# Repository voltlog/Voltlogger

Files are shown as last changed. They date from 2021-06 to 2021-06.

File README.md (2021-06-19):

# Voltlogger
This repository contains the source files for the Voltlogger, a 10 channel thermocouple data logger built around the ESP32 and the MAX31855 thermocouple interface chip. This project was shown in Voltlog #368.

## Known bugs in revA
Schematic constains a bug, where IO34 & IO35 are connected to chip select signals for thermocouple interface chips #1 and #2. These pins are input only on the ESP32 so they cannot drive the CS pis on Th1 & Th2. The workaround is to connect these CS pins to IO22 and IO23. ESD protection diodes seem to be causing signal integrity issues on the SD card interface so leave those unpopulated until this issue is debugged further.

More info about this project in [Voltlog #368](https://youtu.be/YB1_f1XHdw0).
If you would like to order one of these boards ready assembled, check out my [Tindie store](https://www.tindie.com/products/voltlog/voltlogger-10-channel-thermocouple-data-logger/).

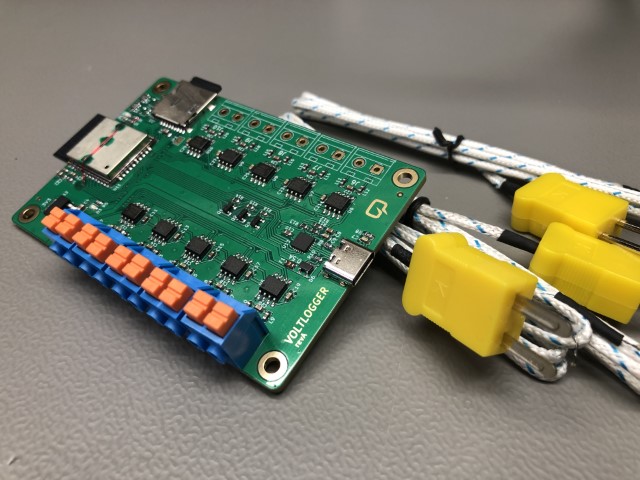
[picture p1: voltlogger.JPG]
Image of the assembled PCB


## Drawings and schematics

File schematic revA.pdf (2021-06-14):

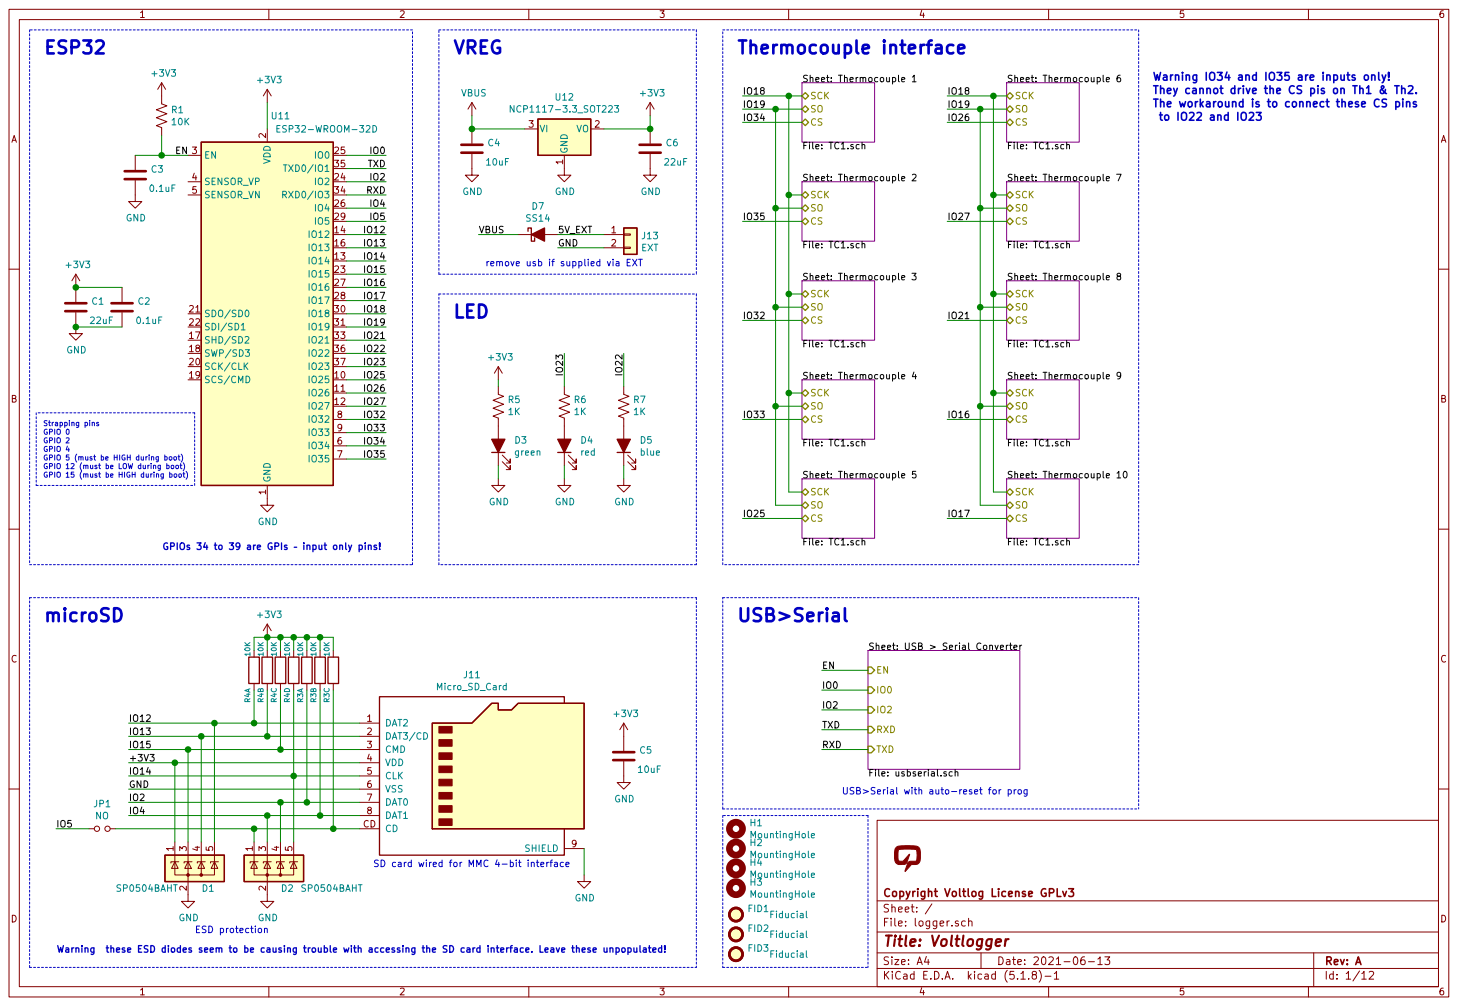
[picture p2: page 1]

Sheet: Thermocouple 1 File: TC1.sch SCK

Sheet: Thermocouple 6 File: TC1.sch SCK

Warning IO34 and IO35 are inputs only!
They cannot drive the CS pis on Th1 & Th2.
The workaround is to connect these CS pins

2 SCK/CLK 20 SDO/SD0 21 SDI/SD1 22

Sheet: Thermocouple 2 File: TC1.sch SCK

Sheet: Thermocouple 7 File: TC1.sch SCK

remove usb if supplied via EXT

Sheet: Thermocouple 3 File: TC1.sch SCK

Sheet: Thermocouple 8 File: TC1.sch SCK

Sheet: Thermocouple 4 File: TC1.sch SCK

Sheet: Thermocouple 9 File: TC1.sch SCK

Strapping pins GPIO 0 GPIO 2 GPIO 4 GPIO 5 (must be HIGH during boot) GPIO 12 (must be LOW during boot) GPIO 15 (must be HIGH during boot)

IO35 Warning these ESD diodes seem to be causing trouble with accessing the SD card interface. Leave these unpopulated!

Sheet: Thermocouple 5 File: TC1.sch SCK

Sheet: Thermocouple 10 File: TC1.sch SCK

Sheet: USB > Serial Converter File: usbserial.sch EN

USB>Serial with auto-reset for prog

File: logger.sch Sheet: / Copyright Voltlog License GPLv3

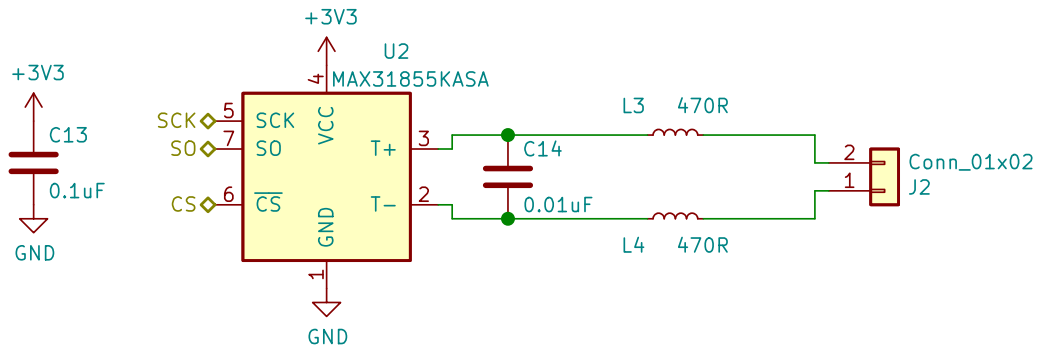
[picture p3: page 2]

4 SCK 5 CS 6 SO 7 U2 MAX31855KASA CS

Id: 2/12 Title: File: TC1.sch Sheet: /Thermocouple 2/

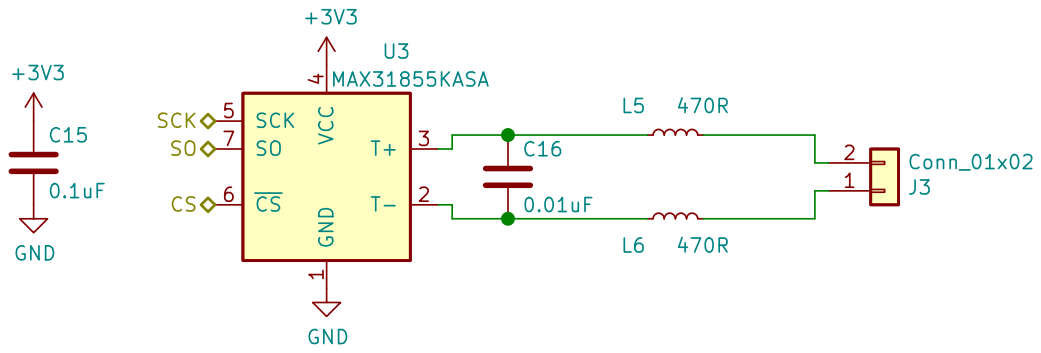
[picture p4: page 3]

4 SCK 5 CS 6 SO 7 U3 MAX31855KASA CS

Id: 3/12 Title: File: TC1.sch Sheet: /Thermocouple 3/

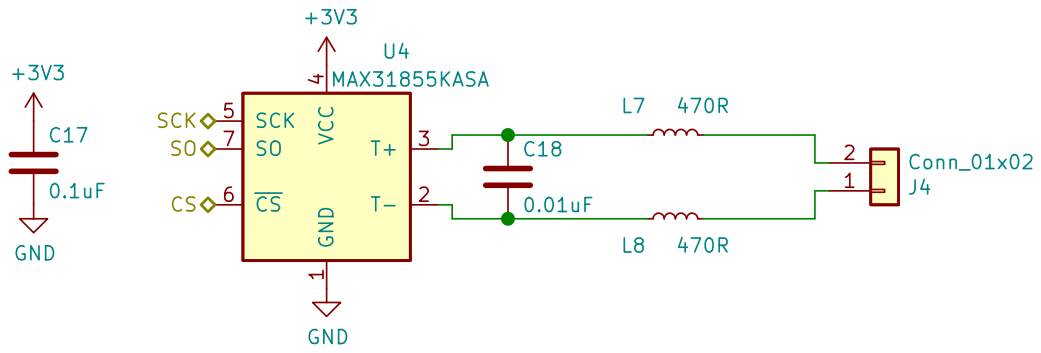
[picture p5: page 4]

4 SCK 5 CS 6 SO 7 U4 MAX31855KASA CS

Id: 4/12 Title: File: TC1.sch Sheet: /Thermocouple 4/

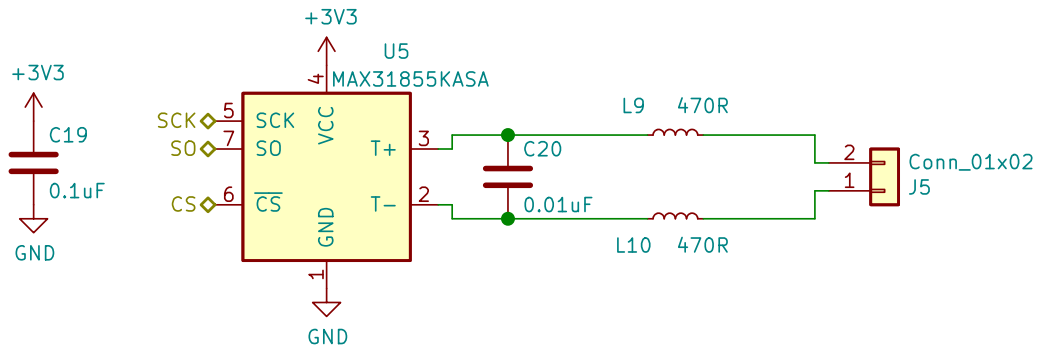
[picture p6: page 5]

4 SCK 5 CS 6 SO 7 U5 MAX31855KASA CS

Id: 5/12 Title: File: TC1.sch Sheet: /Thermocouple 5/

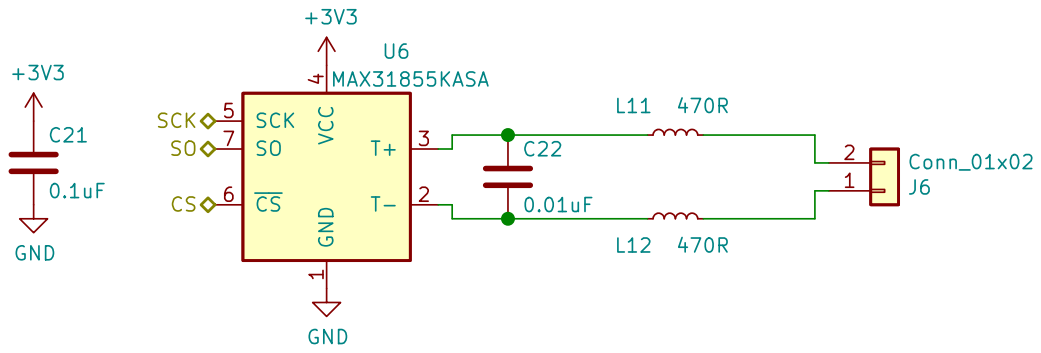
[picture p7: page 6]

4 SCK 5 CS 6 SO 7 U6 MAX31855KASA CS

Id: 6/12 Title: File: TC1.sch Sheet: /Thermocouple 6/

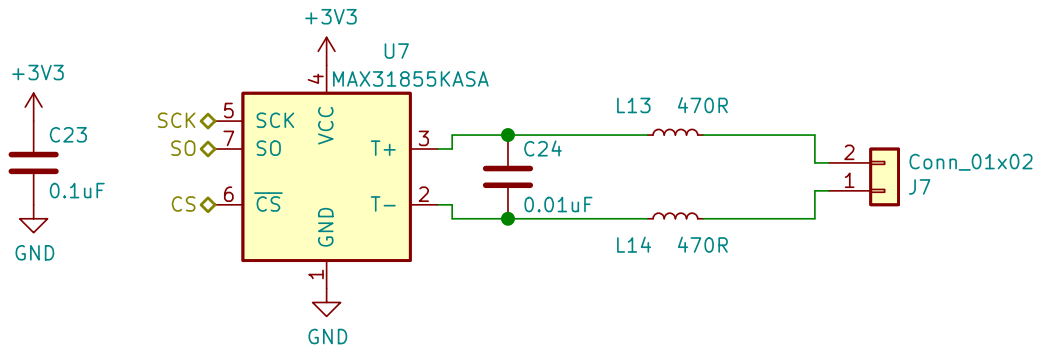
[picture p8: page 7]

4 SCK 5 CS 6 SO 7 U7 MAX31855KASA CS

Id: 7/12 Title: File: TC1.sch Sheet: /Thermocouple 7/

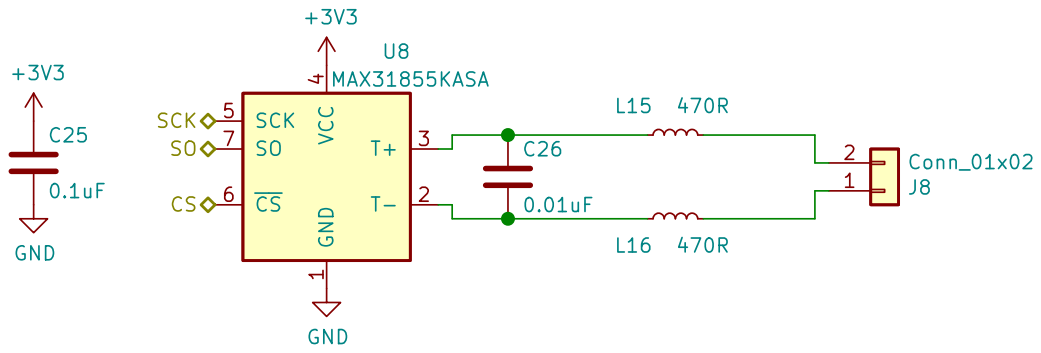
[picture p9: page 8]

4 SCK 5 CS 6 SO 7 U8 MAX31855KASA CS

Id: 8/12 Title: File: TC1.sch Sheet: /Thermocouple 8/

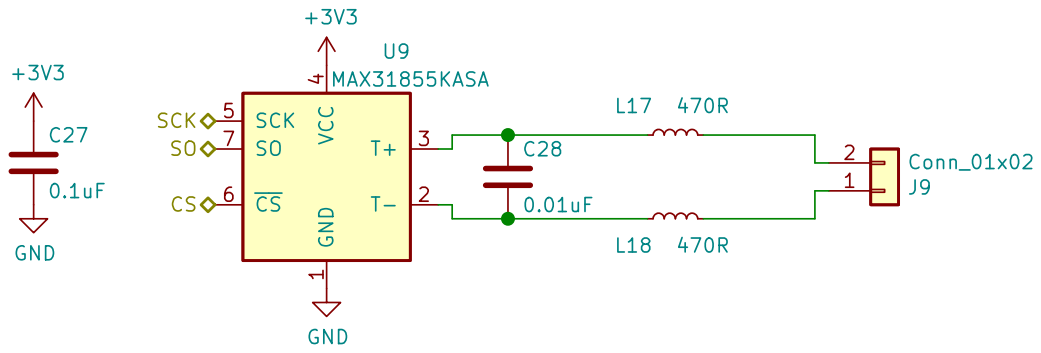
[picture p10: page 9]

4 SCK 5 CS 6 SO 7 U9 MAX31855KASA CS

Id: 9/12 Title: File: TC1.sch Sheet: /Thermocouple 9/

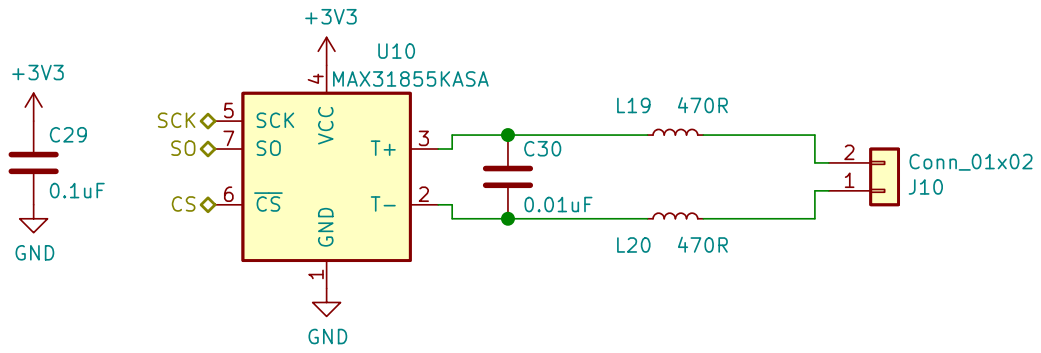
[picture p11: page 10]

4 SCK 5 CS 6 SO 7 U10 MAX31855KASA CS

Id: 10/12 Title: File: TC1.sch Sheet: /Thermocouple 10/

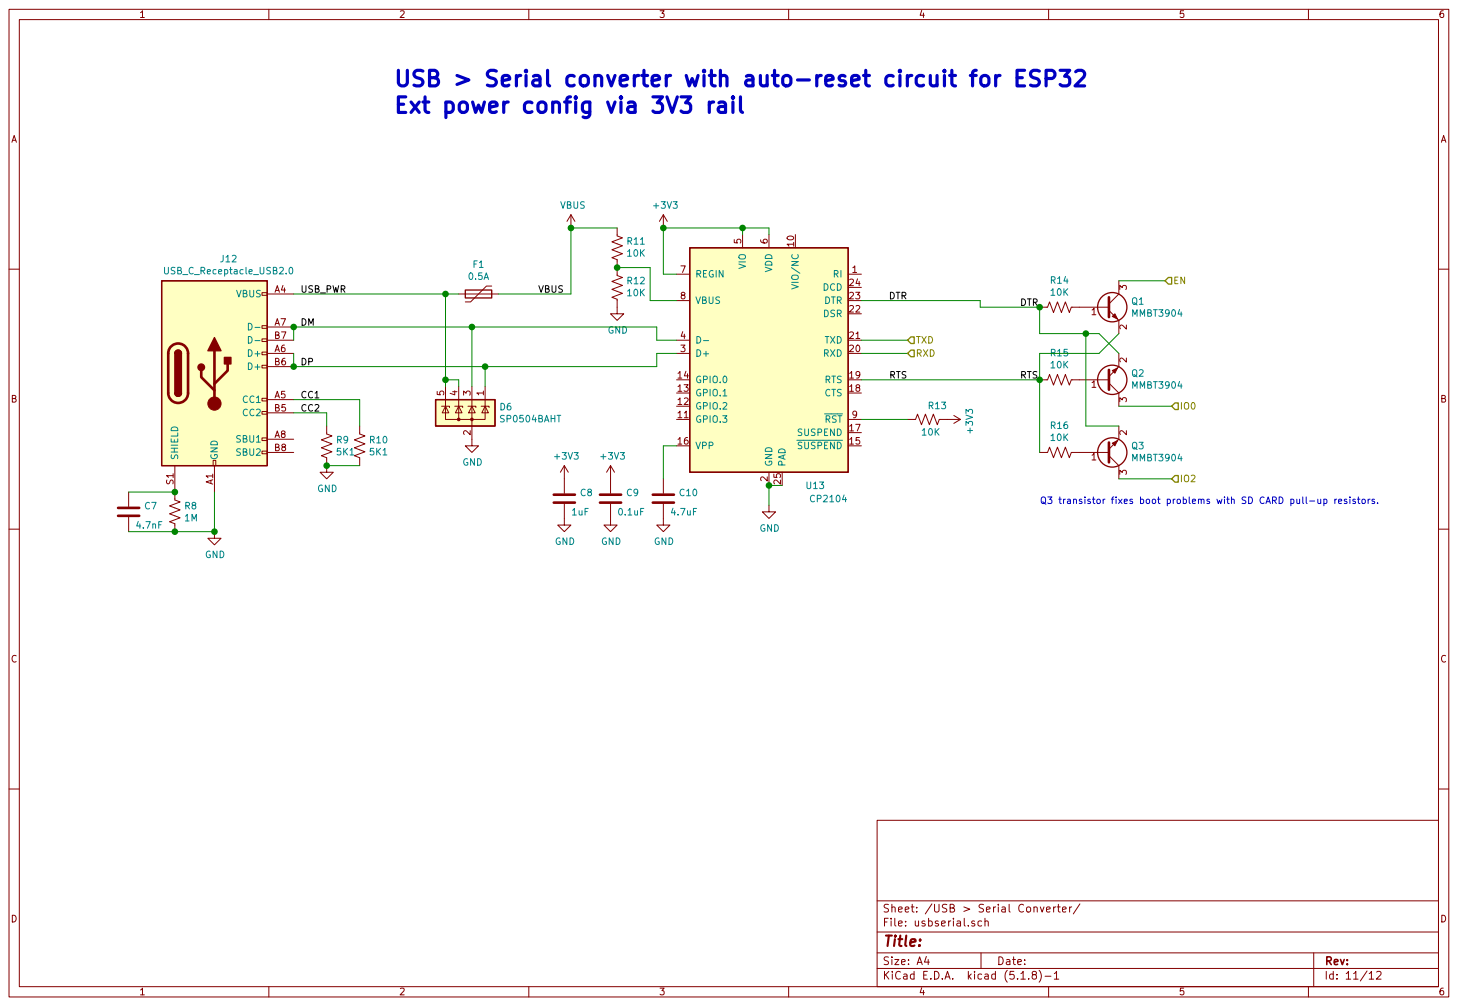
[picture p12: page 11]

Ext power config via 3V3 rail

6 REGIN 7 VBUS 8 RST 9 U13 CP2104 +3V3 GND

2 RXD 20 TXD 21 DSR 22 DTR 23 DCD 24 PAD 25 D+ 3 D- 4 VIO

Q3 transistor fixes boot problems with SD CARD pull-up resistors.

Id: 11/12 Title: File: usbserial.sch Sheet: /USB > Serial Converter/ GND

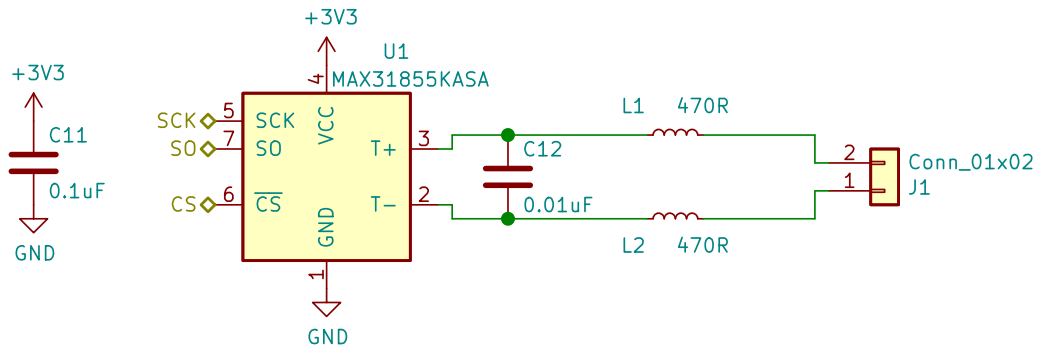
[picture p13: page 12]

4 SCK 5 CS 6 SO 7 U1 MAX31855KASA CS

Id: 12/12 Title: File: TC1.sch Sheet: /Thermocouple 1/

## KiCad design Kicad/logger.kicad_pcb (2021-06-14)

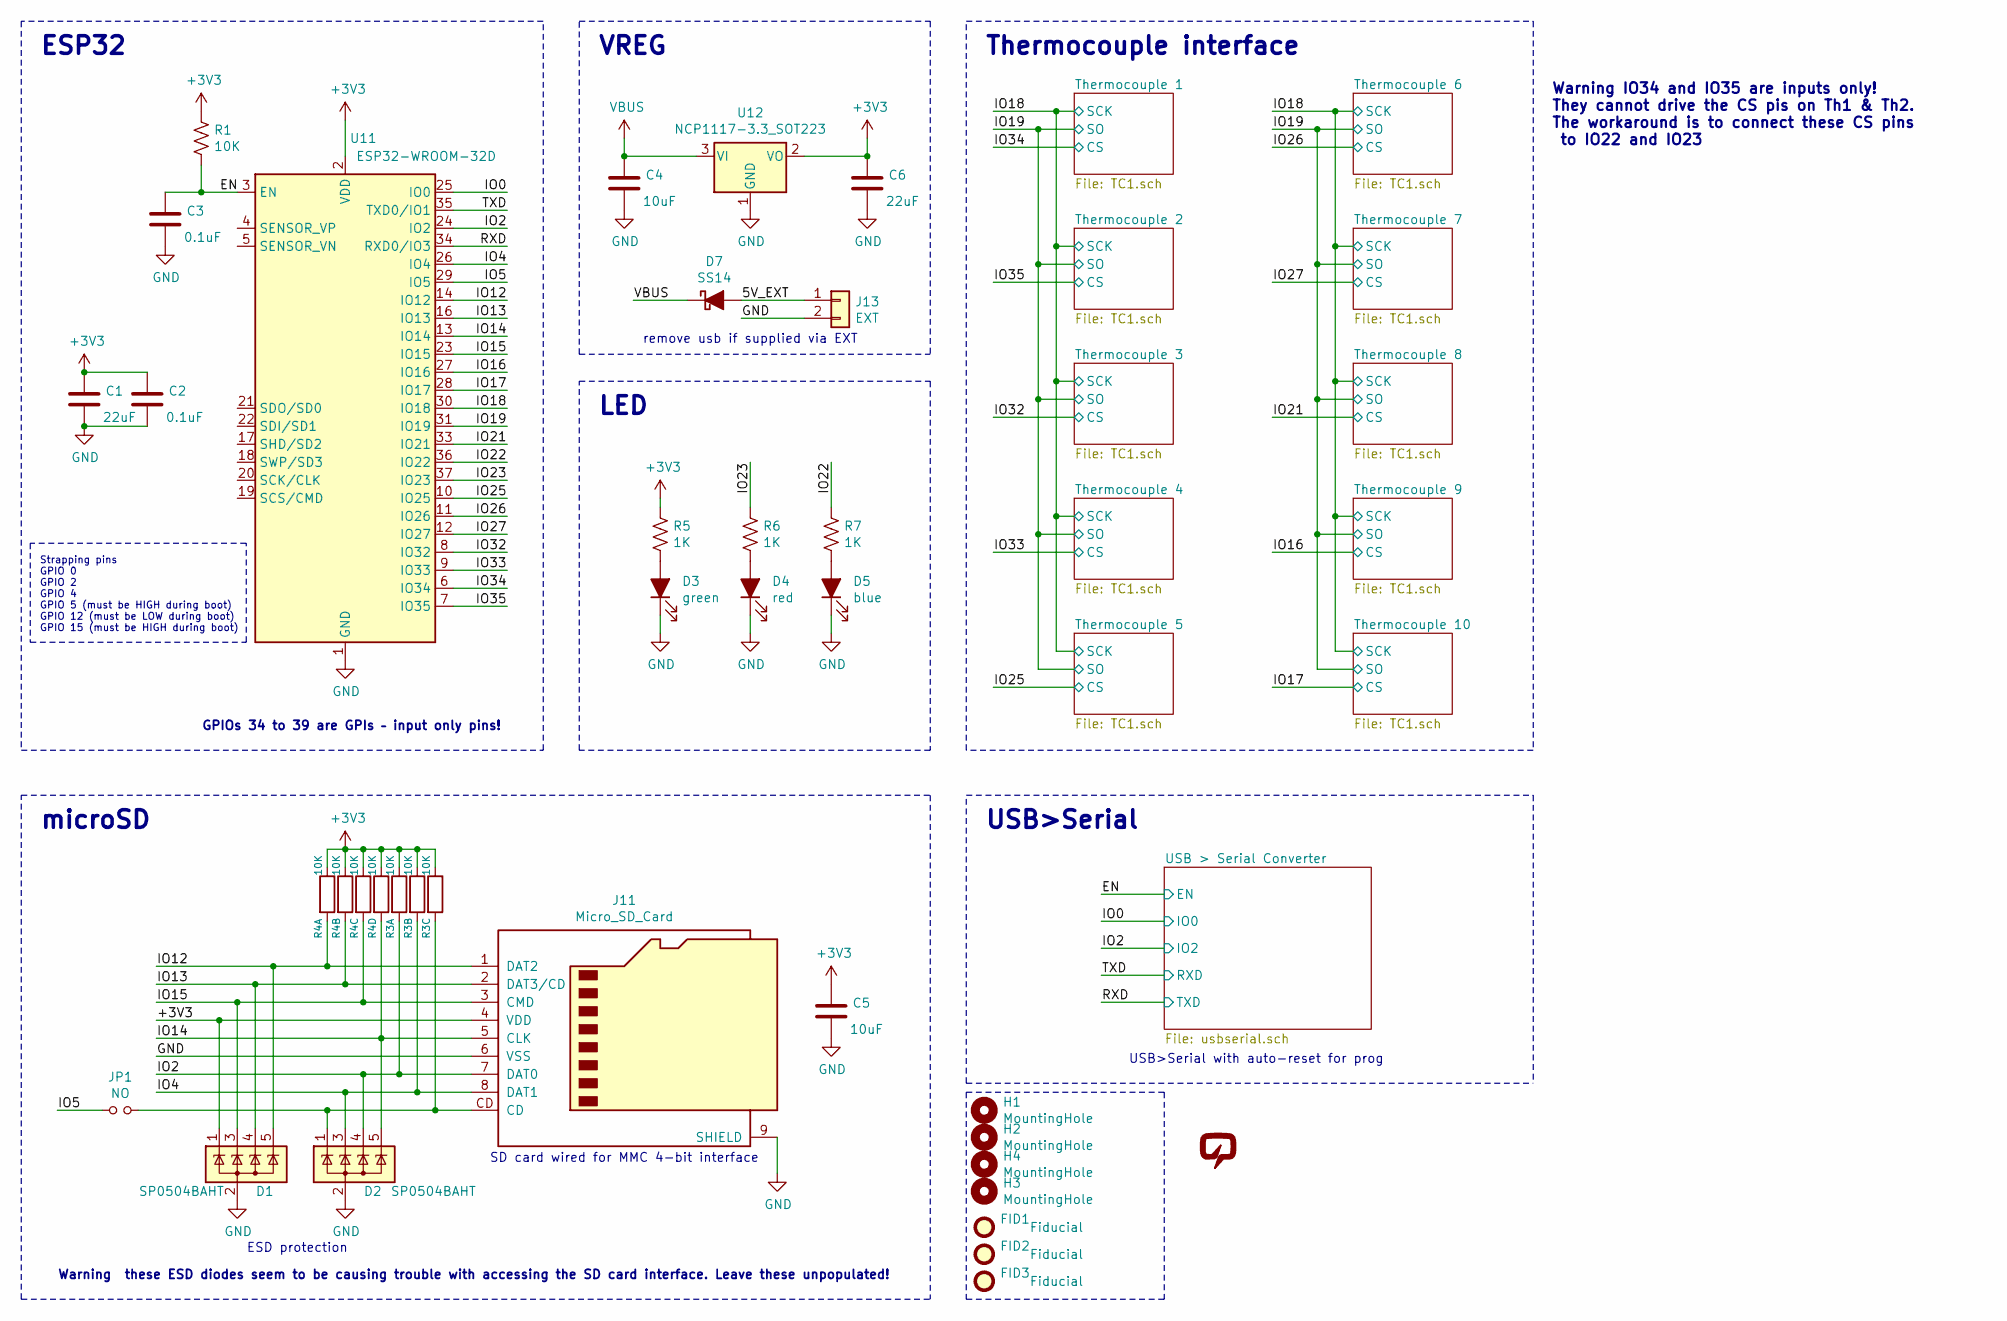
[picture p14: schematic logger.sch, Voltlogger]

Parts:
C1, C6: 22uF; C_0805_2012Metric
C2, C3: 0.1uF; C_0603_1608Metric
C4, C5: 10uF; C_0805_2012Metric
D1, D2: SP0504BAHT; SOT-23-5
D3: green; LED_0603_1608Metric
D4: red; LED_0603_1608Metric
D5: blue; LED_0603_1608Metric
D7: SS14; D_SMA
FID1, FID2, FID3: Fiducial; Fiducial_0.75mm_Mask1.5mm
H1, H2, H3, H4: MountingHole; MountingHole_3.2mm_M3_ISO7380_Pad
J11: Micro_SD_Card; XKTF-015-N
J13: EXT; PinHeader_1x02_P2.54mm_Vertical
JP1: NO; SolderJumper-2_P1.3mm_Open_TrianglePad1.0x1.5mm
R1: 10K; R_0603_1608Metric
R3, R4: 10K; R_Array_Convex_4x0603
R5, R6, R7: 1K; R_0603_1608Metric
U11: ESP32-WROOM-32D; ESP32-WROOM-32
U12: NCP1117-3.3_SOT223; SOT-223-3_TabPin2
V1: VOLTLOG_LOGO; voltlog_mask_5mm

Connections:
+3V3: C1.1, C2.1, C5.1, C6.1, D1.1 (K), J11.4 (VDD), R1.1, R3.6, R3.7, R3.8, R4.5, R4.6, R4.7, R4.8, R5.2, U11.2 (VDD), U12.2 (VO); also elsewhere on the board
/5V_EXT: D7.2 (A), J13.1
/EN: C3.1, R1.2, U11.3 (EN); also elsewhere on the board
/IO0: U11.25 (IO0); also elsewhere on the board
/IO2: D2.4 (K), J11.7 (DAT0), R3.1, U11.24 (IO2); also elsewhere on the board
/IO4: D2.3 (K), J11.8 (DAT1), R3.2, U11.26 (IO4)
/IO5: JP1.2, U11.29 (IO5)
/IO12: D1.5 (K), J11.1 (DAT2), R4.1, U11.14 (IO12)
/IO13: D1.4 (K), J11.2 (DAT3/CD), R4.2, U11.16 (IO13)
/IO14: D2.5 (K), J11.5 (CLK), R4.4, U11.13 (IO14)
/IO15: D1.3 (K), J11.3 (CMD), R4.3, U11.23 (IO15)
/IO16: U11.27 (IO16); also elsewhere on the board
/IO17: U11.28 (IO17); also elsewhere on the board
/IO18: U11.30 (IO18); also elsewhere on the board
/IO19: U11.31 (IO19); also elsewhere on the board
/IO21: U11.33 (IO21); also elsewhere on the board
/IO22: R7.2, U11.36 (IO22)
/IO23: R6.2, U11.37 (IO23)
/IO25: U11.10 (IO25); also elsewhere on the board
/IO26: U11.11 (IO26); also elsewhere on the board
/IO27: U11.12 (IO27); also elsewhere on the board
/IO32: U11.8 (IO32); also elsewhere on the board
/IO33: U11.9 (IO33); also elsewhere on the board
/IO34: U11.6 (IO34); also elsewhere on the board
/IO35: U11.7 (IO35); also elsewhere on the board
/RXD: U11.34 (RXD0/IO3); also elsewhere on the board
/TXD: U11.35 (TXD0/IO1); also elsewhere on the board
GND: C1.2, C2.2, C3.2, C4.2, C5.2, C6.2, D1.2 (A), D2.2 (A), D3.1 (K), D4.1 (K), D5.1 (K), J11.6 (VSS), J11.9 (SHIELD), J13.2, U11.1 (GND), U11.15 (GND), U11.38 (GND), U11.39 (GND), U12.1 (GND); also elsewhere on the board
unnamed: D2.1 (K), J11.CD, JP1.1, R3.3
unnamed: D3.2 (A), R5.1
unnamed: D4.2 (A), R6.1
unnamed: D5.2 (A), R7.1
VBUS: C4.1, D7.1 (K), U12.3 (VI); also elsewhere on the board

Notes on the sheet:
SD card wired for MMC 4-bit interface
Strapping pins GPIO 0 GPIO 2 GPIO 4 GPIO 5 (must be HIGH during boot) GPIO 12 (must be LOW during boot) GPIO 15 (must be HIGH during boot)
ESP32
VREG
remove usb if supplied via EXT
LED
microSD
ESD protection
Thermocouple interface
USB>Serial
USB>Serial with auto-reset for prog
GPIOs 34 to 39 are GPIs – input only pins!
Warning IO34 and IO35 are inputs only! They cannot drive the CS pis on Th1 & Th2. The workaround is to connect these CS pins to IO22 and IO23
Warning these ESD diodes seem to be causing trouble with accessing the SD card interface. Leave these unpopulated!

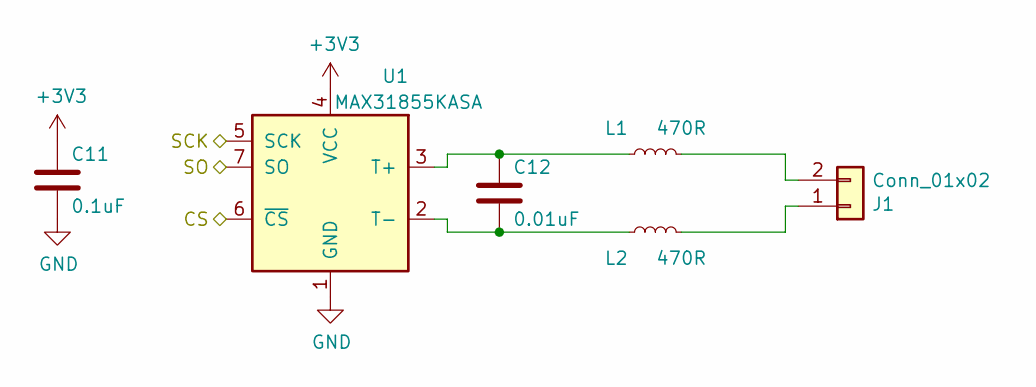
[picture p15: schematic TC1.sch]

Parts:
C11: 0.1uF; C_0603_1608Metric
C12: 0.01uF; C_0603_1608Metric
J1: Conn_01x02; TerminalBlock_MetzConnect_Type094_RT03502HBLU_1x02_P5.00mm_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
L1, L2: 470R; L_0603_1608Metric
U1: MAX31855KASA; SOIC-8_3.9x4.9mm_P1.27mm

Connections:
+3V3: C11.1, U1.4 (VCC); also elsewhere on the board
/IO18: U1.5 (SCK); also elsewhere on the board
/IO19: U1.7 (SO); also elsewhere on the board
/IO34: U1.6 (~CS~); also elsewhere on the board
GND: C11.2, U1.1 (GND); also elsewhere on the board
unnamed: C12.1, L1.1, U1.3 (T+)
unnamed: C12.2, L2.1, U1.2 (T-)
unnamed: J1.1, L2.2
unnamed: J1.2, L1.2

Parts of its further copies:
C13, C15, C17, C19, C21, C23, C25, C27, C29: 0.1uF; C_0603_1608Metric
C14, C16, C18, C20, C22, C24, C26, C28, C30: 0.01uF; C_0603_1608Metric
J2, J3, J4, J5, J6, J7, J8, J9, J10: Conn_01x02; TerminalBlock_MetzConnect_Type094_RT03502HBLU_1x02_P5.00mm_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
L3, L4, L5, L6, L7, L8, L9, L10, L11, L12, L13, L14, L15, L16, L17, L18, L19, L20: 470R; L_0603_1608Metric
U2, U3, U4, U5, U6, U7, U8, U9, U10: MAX31855KASA; SOIC-8_3.9x4.9mm_P1.27mm

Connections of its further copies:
+3V3: C13.1, C15.1, C17.1, C19.1, C21.1, C23.1, C25.1, C27.1, C29.1, U2.4 (VCC), U3.4 (VCC), U4.4 (VCC), U5.4 (VCC), U6.4 (VCC), U7.4 (VCC), U8.4 (VCC), U9.4 (VCC), U10.4 (VCC); also elsewhere on the board
/IO16: U9.6 (~CS~); also elsewhere on the board
/IO17: U10.6 (~CS~); also elsewhere on the board
/IO18: U2.5 (SCK), U3.5 (SCK), U4.5 (SCK), U5.5 (SCK), U6.5 (SCK), U7.5 (SCK), U8.5 (SCK), U9.5 (SCK), U10.5 (SCK); also elsewhere on the board
/IO19: U2.7 (SO), U3.7 (SO), U4.7 (SO), U5.7 (SO), U6.7 (SO), U7.7 (SO), U8.7 (SO), U9.7 (SO), U10.7 (SO); also elsewhere on the board
/IO21: U8.6 (~CS~); also elsewhere on the board
/IO25: U5.6 (~CS~); also elsewhere on the board
/IO26: U6.6 (~CS~); also elsewhere on the board
/IO27: U7.6 (~CS~); also elsewhere on the board
/IO32: U3.6 (~CS~); also elsewhere on the board
/IO33: U4.6 (~CS~); also elsewhere on the board
/IO35: U2.6 (~CS~); also elsewhere on the board
GND: C13.2, C15.2, C17.2, C19.2, C21.2, C23.2, C25.2, C27.2, C29.2, U2.1 (GND), U3.1 (GND), U4.1 (GND), U5.1 (GND), U6.1 (GND), U7.1 (GND), U8.1 (GND), U9.1 (GND), U10.1 (GND); also elsewhere on the board
unnamed: C14.1, L3.1, U2.3 (T+)
unnamed: C14.2, L4.1, U2.2 (T-)
unnamed: C16.1, L5.1, U3.3 (T+)
unnamed: C16.2, L6.1, U3.2 (T-)
unnamed: C18.1, L7.1, U4.3 (T+)
unnamed: C18.2, L8.1, U4.2 (T-)
unnamed: C20.1, L9.1, U5.3 (T+)
unnamed: C20.2, L10.1, U5.2 (T-)
unnamed: C22.1, L11.1, U6.3 (T+)
unnamed: C22.2, L12.1, U6.2 (T-)
unnamed: C24.1, L13.1, U7.3 (T+)
unnamed: C24.2, L14.1, U7.2 (T-)
unnamed: C26.1, L15.1, U8.3 (T+)
unnamed: C26.2, L16.1, U8.2 (T-)
unnamed: C28.1, L17.1, U9.3 (T+)
unnamed: C28.2, L18.1, U9.2 (T-)
unnamed: C30.1, L19.1, U10.3 (T+)
unnamed: C30.2, L20.1, U10.2 (T-)
unnamed: J2.1, L4.2
unnamed: J2.2, L3.2
unnamed: J3.1, L6.2
unnamed: J3.2, L5.2
unnamed: J4.1, L8.2
unnamed: J4.2, L7.2
unnamed: J5.1, L10.2
unnamed: J5.2, L9.2
unnamed: J6.1, L12.2
unnamed: J6.2, L11.2
unnamed: J7.1, L14.2
unnamed: J7.2, L13.2
unnamed: J8.1, L16.2
unnamed: J8.2, L15.2
unnamed: J9.1, L18.2
unnamed: J9.2, L17.2
unnamed: J10.1, L20.2
unnamed: J10.2, L19.2

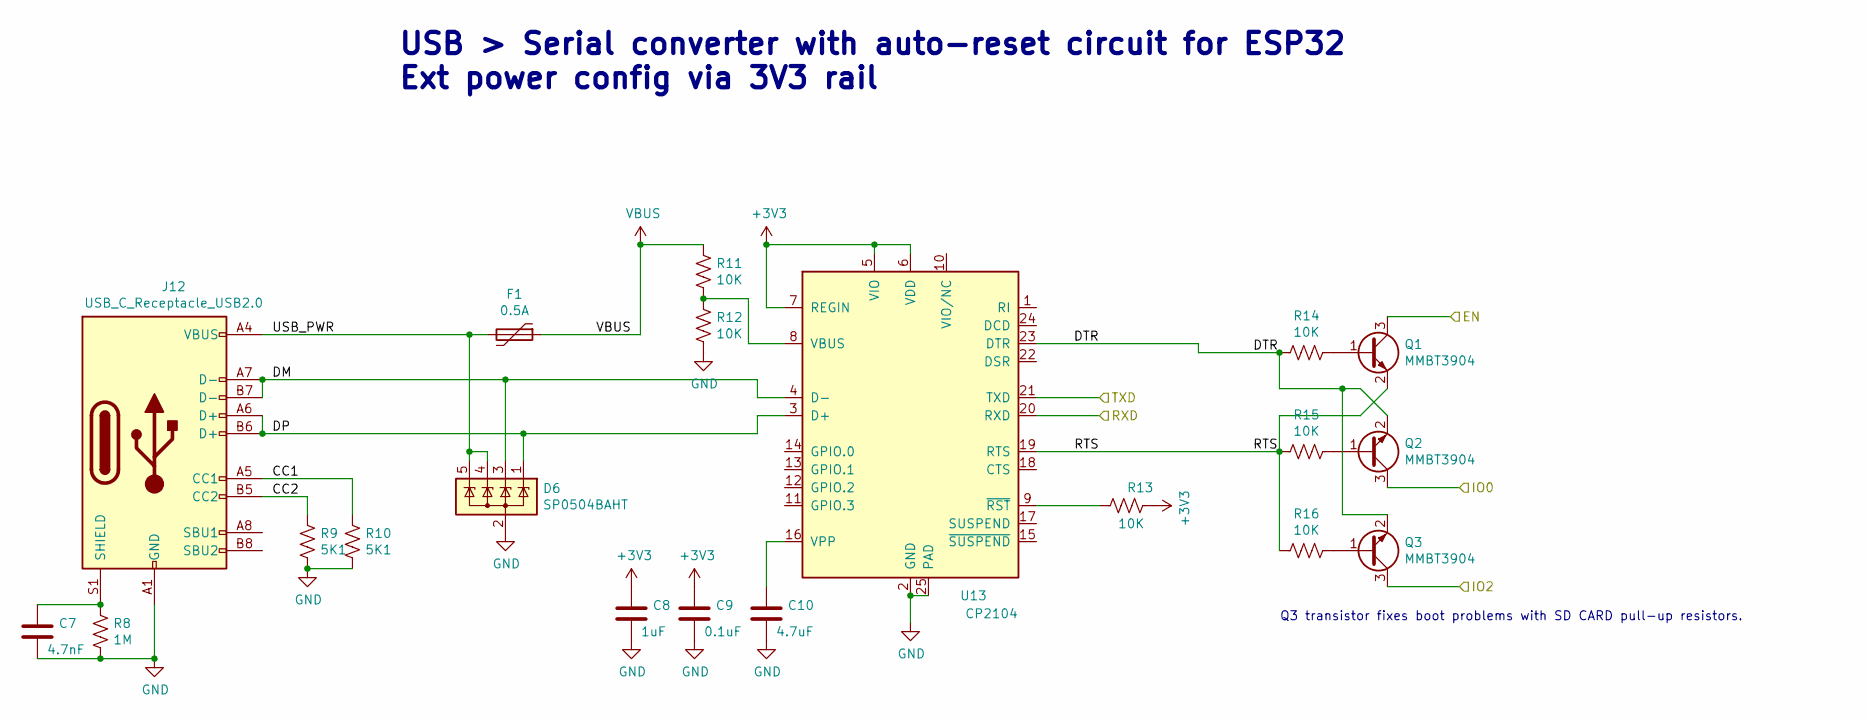
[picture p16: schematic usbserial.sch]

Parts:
C7: 4.7nF; C_0603_1608Metric
C8: 1uF; C_0603_1608Metric
C9: 0.1uF; C_0603_1608Metric
C10: 4.7uF; C_0603_1608Metric
D6: SP0504BAHT; SOT-23-5
F1: 0.5A; Fuse_0805_2012Metric
J12: USB_C_Receptacle_USB2.0; TYPE-C-31-M-12
Q1, Q2, Q3: MMBT3904; SOT-23
R8: 1M; R_0603_1608Metric
R9, R10: 5K1; R_0603_1608Metric
R11, R12, R13, R14, R15, R16: 10K; R_0603_1608Metric
U13: CP2104; QFN-24-1EP_4x4mm_P0.5mm_EP2.6x2.6mm

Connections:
+3V3: C8.1, C9.1, R13.2, U13.5 (VIO), U13.6 (VDD), U13.7 (REGIN); also elsewhere on the board
/EN: Q1.3 (C); also elsewhere on the board
/IO0: Q2.3 (C); also elsewhere on the board
/IO2: Q3.3 (C); also elsewhere on the board
/RXD: U13.21 (TXD); also elsewhere on the board
/TXD: U13.20 (RXD); also elsewhere on the board
/USB > Serial Converter/CC1: J12.A5 (CC1), R10.1
/USB > Serial Converter/CC2: J12.B5 (CC2), R9.1
/USB > Serial Converter/DM: D6.3 (K), J12.A7 (D-), J12.B7 (D-), U13.4 (D-)
/USB > Serial Converter/DP: D6.1 (K), J12.A6 (D+), J12.B6 (D+), U13.3 (D+)
/USB > Serial Converter/DTR: Q2.2 (E), Q3.2 (E), R14.2, U13.23 (DTR)
/USB > Serial Converter/RTS: Q1.2 (E), R15.2, R16.2, U13.19 (RTS)
/USB > Serial Converter/USB_PWR: D6.4 (K), D6.5 (K), F1.2, J12.A4 (VBUS), J12.A9 (VBUS), J12.B4 (VBUS), J12.B9 (VBUS)
GND: C7.2, C8.2, C9.2, C10.2, D6.2 (A), J12.A1 (GND), J12.A12 (GND), J12.B1 (GND), J12.B12 (GND), R8.2, R9.2, R10.2, R12.1, U13.2 (GND), U13.25 (PAD); also elsewhere on the board
unnamed: C7.1, J12.S1 (SHIELD), R8.1
unnamed: C10.1, U13.16 (VPP)
unnamed: Q1.1 (B), R14.1
unnamed: Q2.1 (B), R15.1
unnamed: Q3.1 (B), R16.1
unnamed: R11.1, R12.2, U13.8 (VBUS)
unnamed: R13.1, U13.9 (~RST)
VBUS: F1.1, R11.2; also elsewhere on the board

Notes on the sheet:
USB > Serial converter with auto-reset circuit for ESP32 Ext power config via 3V3 rail
Q3 transistor fixes boot problems with SD CARD pull-up resistors.

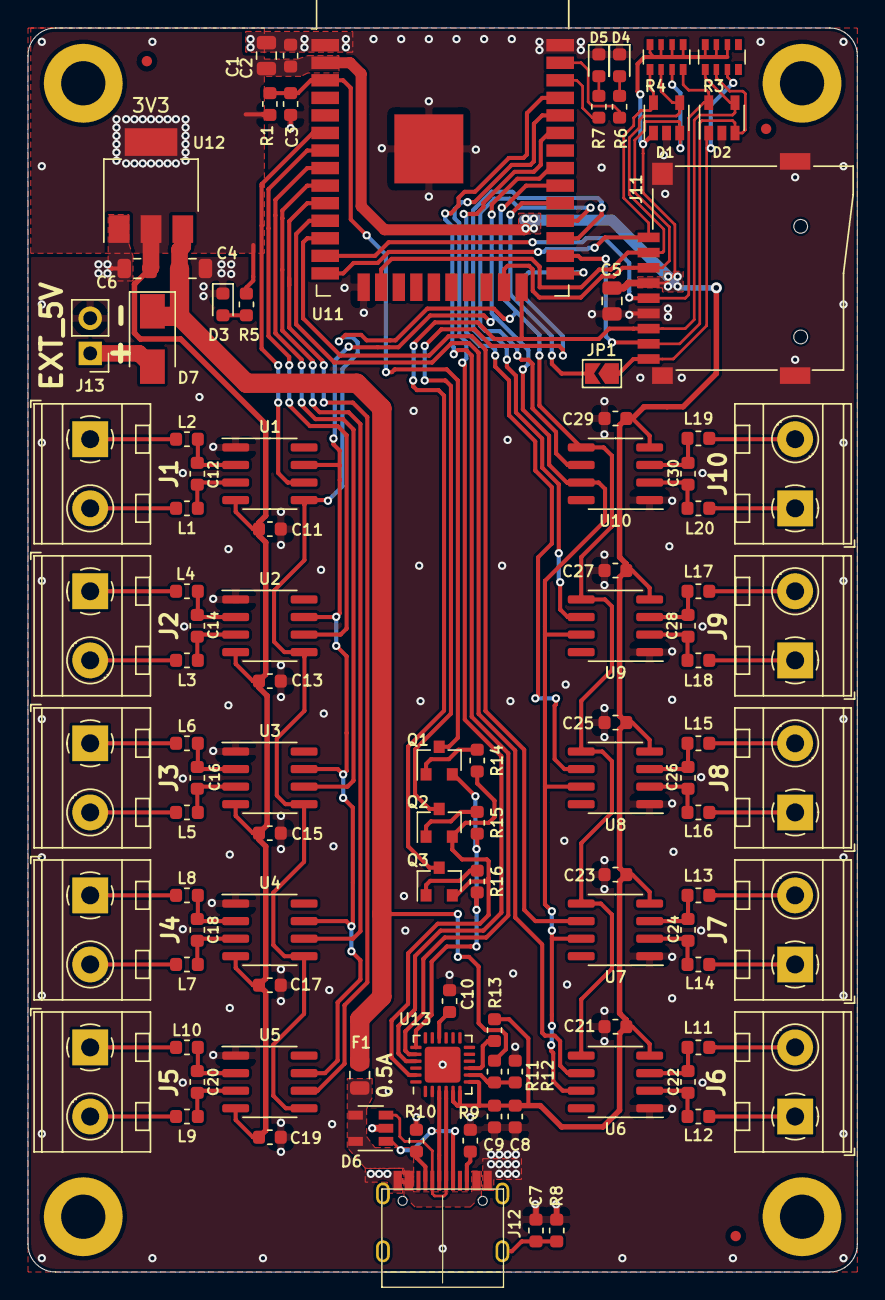
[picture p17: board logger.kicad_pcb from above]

Board: 2 copper layers, 60.0 x 90.0 mm, 111 parts (0 on the bottom side), 87 nets.

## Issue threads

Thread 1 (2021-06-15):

Tindie link is broken

NeoFromMatrix, 2021-06-15:
Tindie link in the main Readme.md redirects to https://www.tindie.com/stores/products/ which shows a tindie 404 page

magicsmoke, 2021-06-16:
It might be a valid link but the listing is hidden for the moment before it is ready to be sold!

voltlog, 2021-06-16:
> Tindie link in the main Readme.md redirects to https://www.tindie.com/stores/products/ which shows a tindie 404 page

Sorry, I'm working on adding the new listing on Tindie, I'll update the link soon.

voltlog, 2021-06-22:
Product is now live on Tindie.

Closed 2021-06-22.

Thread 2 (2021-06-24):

USB-C Receptical

matti04, 2021-06-24:
Hello, thank you for your design. I was looking for a source for your USB-C plug, as I couldn't find one that also has data pins. Can you provide a link to the product you used?

voltlog, 2021-06-30:
Part number is Korean Hroparts Elec TYPE-C-31-M-12. I usually specify the pn for these parts in the symbol properties in the schematic editor.

matti04, 2021-06-30:
Thank you very much, sir!

Closed 2021-06-30.

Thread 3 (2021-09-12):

PID Controller Thermostat

mail87523, 2021-09-12:
I have an idea for you to make one universal esp32 PID Controller with 4 channel thermocouple 4 channel pwm output
for dimmer and Webserver interface as
ESP32 Async WebServer WebSocket JSON PID Controller Thermostat published on github by me.
What do you think about that ?

voltlog, 2021-09-13:
This is not an issue with the current project.

Closed 2021-09-13.

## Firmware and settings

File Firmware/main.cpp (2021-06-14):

/*
Demo firmware for the Voltlogger a 10 ch thermocouple data logging system
As shown in Voltlog #368

lib_deps = adafruit/Adafruit MAX31855 library@^1.3.0

Copyright Voltlog 2021
License: GPLv3
*/
#include <Arduino.h>
#include <WiFi.h>
#include <Wire.h>
#include <SPI.h>
#include <WiFiUdp.h>
#include "Adafruit_MAX31855.h"
#include "FS.h"
#include "SD_MMC.h"
#include "time.h"

// LED pins are also used for thermocouple 1 & 2 chip select
#define BLUE_LED 22
#define RED_LED 23

const char* ssid       = "SSID";
const char* password   = "PASSWORD";

// NTP config
const char* ntpServer = "pool.ntp.org";
const long  gmtOffset_sec = 7200; //GMT+1 = 3600, GMT+2 = 7200
const int   daylightOffset_sec = 3600; 

// Example creating a thermocouple instance with software SPI on any three
// digital IO pins.
#define MAXDO   19
#define MAXCLK  18
#define MAXCS1  22
#define MAXCS2  23 
#define MAXCS3  32
#define MAXCS4  33 
#define MAXCS5  25 
#define MAXCS6  26 
#define MAXCS7  27 
#define MAXCS8  21 
#define MAXCS9  16 
#define MAXCS10 17 

// Initialize the Thermocouple Amplifiers
Adafruit_MAX31855 thermocouple1(MAXCLK, MAXCS1, MAXDO);
Adafruit_MAX31855 thermocouple2(MAXCLK, MAXCS2, MAXDO);
Adafruit_MAX31855 thermocouple3(MAXCLK, MAXCS3, MAXDO);
Adafruit_MAX31855 thermocouple4(MAXCLK, MAXCS4, MAXDO);
Adafruit_MAX31855 thermocouple5(MAXCLK, MAXCS5, MAXDO);
Adafruit_MAX31855 thermocouple6(MAXCLK, MAXCS6, MAXDO);
Adafruit_MAX31855 thermocouple7(MAXCLK, MAXCS7, MAXDO);
Adafruit_MAX31855 thermocouple8(MAXCLK, MAXCS8, MAXDO);
Adafruit_MAX31855 thermocouple9(MAXCLK, MAXCS9, MAXDO);
Adafruit_MAX31855 thermocouple10(MAXCLK, MAXCS10, MAXDO);

// Variables to save date and time
String timeStamp;

// Variables to save temp readings
double t1;
double t2;
double t3;
double t4;
double t5;
double t6;
double t7;
double t8;
double t9;
double t10;

String dataMessage;

// Save reading number on RTC memory
RTC_DATA_ATTR int readingID = 0;

// Declare functions
void initialize_thermocouples(void);
void print_sensors(void);
void read_sensors(void);
void initSDcard(void);
void getTimeStamp(void);
void logSDCard();
void writeFile(fs::FS &fs, const char * path, const char * message);
void appendFile(fs::FS &fs, const char * path, const char * message);
void printLocalTime(void);

void setup() {
  // put your setup code here, to run once:
  // Init UART interface
  Serial.begin(115200);
  Serial.println("VOLTLOG Thermocouple Data Logging System");

  pinMode(RED_LED, OUTPUT);
  pinMode(BLUE_LED, OUTPUT);

      // Init & connect to WiFi
  Serial.printf("Connecting to %s ", ssid);
  WiFi.begin(ssid, password);
  while (WiFi.status() != WL_CONNECTED) {
      delay(500);
      Serial.print(".");
  }
  Serial.println(" CONNECTED");
  Serial.print("Got IP: ");  Serial.println(WiFi.localIP());

   // Init and get the time
  configTime(gmtOffset_sec, daylightOffset_sec, ntpServer);
  printLocalTime();

  initialize_thermocouples();

  initSDcard();
}

void loop() {
  //print_sensors();
  read_sensors();
  getTimeStamp();
  logSDCard();
  
  // Increment readingID on every new reading
  readingID++;

  delay(1000);
}

void initialize_thermocouples(void) {
  
  Serial.println("Initializing thermocouple sensors...");

  if (!thermocouple1.begin()) {
    Serial.println("ERROR.");
    while (1) delay(10);
  } Serial.print("T1 OK, ");

  if (!thermocouple2.begin()) {
    Serial.println("ERROR.");
    while (1) delay(10);
  } Serial.print("T2 OK, ");

  if (!thermocouple3.begin()) {
    Serial.println("ERROR.");
    while (1) delay(10);
  } Serial.print("T3 OK, ");

  if (!thermocouple4.begin()) {
    Serial.println("ERROR.");
    while (1) delay(10);
  } Serial.print("T4 OK, ");

  if (!thermocouple5.begin()) {
    Serial.println("ERROR.");
    while (1) delay(10);
  } Serial.print("T5 OK, ");

  if (!thermocouple6.begin()) {
    Serial.println("ERROR.");
    while (1) delay(10);
  } Serial.print("T6 OK, ");

  if (!thermocouple7.begin()) {
    Serial.println("ERROR.");
    while (1) delay(10);
  } Serial.print("T7 OK, ");

  if (!thermocouple8.begin()) {
    Serial.println("ERROR.");
    while (1) delay(10);
  } Serial.print("T8 OK, ");

  if (!thermocouple9.begin()) {
    Serial.println("ERROR.");
    while (1) delay(10);
  } Serial.print("T9 OK, ");

  if (!thermocouple10.begin()) {
    Serial.println("ERROR.");
    while (1) delay(10);
  } Serial.print("T10 OK.");

  Serial.print("\r\n");
}

void print_sensors(void) {
// basic readout test, just print the current temp
   Serial.print("#1 Internal Temp = ");
   Serial.println(thermocouple1.readInternal());
   Serial.print("#2 Internal Temp = ");
   Serial.println(thermocouple2.readInternal());
   Serial.print("#3 Internal Temp = ");
   Serial.println(thermocouple3.readInternal());
   Serial.print("#4 Internal Temp = ");
   Serial.println(thermocouple4.readInternal());
   Serial.print("#5 Internal Temp = ");
   Serial.println(thermocouple5.readInternal());
   Serial.print("#6 Internal Temp = ");
   Serial.println(thermocouple6.readInternal());
   Serial.print("#7 Internal Temp = ");
   Serial.println(thermocouple7.readInternal());
   Serial.print("#8 Internal Temp = ");
   Serial.println(thermocouple8.readInternal());
   Serial.print("#9 Internal Temp = ");
   Serial.println(thermocouple9.readInternal());
   Serial.print("#10 Internal Temp = ");
   Serial.println(thermocouple10.readInternal());

}

void read_sensors(void) {
  t1 = thermocouple1.readCelsius();
  t2 = thermocouple1.readCelsius();
  t3 = thermocouple1.readCelsius();
  t4 = thermocouple1.readCelsius();
  t5 = thermocouple1.readCelsius();
  t6 = thermocouple1.readCelsius();
  t7 = thermocouple1.readCelsius();
  t8 = thermocouple1.readCelsius();
  t9 = thermocouple1.readCelsius();
  t10 = thermocouple1.readCelsius();
}

void initSDcard(void) {

  Serial.println("Initializing SD card..");

  if(!SD_MMC.begin()){
     Serial.println("Failed to mount card");
     return;
  }

  uint8_t cardType = SD_MMC.cardType();
  if(cardType == CARD_NONE) {
    Serial.println("No SD card attached");
    return;
  }

  Serial.print("SD Card Type: ");
  if(cardType == CARD_MMC){
    Serial.println("MMC");
  } else if(cardType == CARD_SD){
    Serial.println("SDSC");
  } else if(cardType == CARD_SDHC){
    Serial.println("SDHC");
  } else {
    Serial.println("UNKNOWN");
  }

  uint64_t cardSize = SD_MMC.cardSize() / (1024 * 1024);
  Serial.printf("SD Card Size: %lluMB\n", cardSize);

  // If the data.txt file doesn't exist
  // Create a file on the SD card and write the data labels
  File file = SD_MMC.open("/data.txt");
  if(!file) {
    Serial.println("File doens't exist");
    Serial.println("Creating file...");
    writeFile(SD_MMC, "/data.txt", "Reading ID, Date, Hour, Temperature \r\n");
  }
  else {
    Serial.println("File already exists");  
  }
  file.close();
}

// Function to get date and time from NTPClient
void getTimeStamp(void) {
  struct tm timeinfo;

  if(!getLocalTime(&timeinfo)){
    Serial.println("Failed to obtain time");
    return;
  }

  //extract formatted date & time from timeinfo structure
  char output[50];
  strftime(output, sizeof(output), "%A, %B %d %Y %H:%M:%S", &timeinfo);
  timeStamp = String(output);
}

// Write the sensor readings on the SD card
void logSDCard() {
  dataMessage = String(readingID) + "," + String(timeStamp) + "," + 
                "t1=" + String(t1) +  "," +
                "t2=" + String(t2) +  "," +
                "t3=" + String(t3) +  "," +
                "t4=" + String(t4) +  "," +
                "t5=" + String(t5) +  "," +
                "t6=" + String(t6) +  "," +
                "t7=" + String(t7) +  "," +
                "t8=" + String(t8) +  "," +
                "t9=" + String(t9) +  "," +
                "t10=" + String(t10) + "\r\n";
  Serial.print("Message: ");
  Serial.print(dataMessage);
  appendFile(SD_MMC, "/data.txt", dataMessage.c_str());
}

// Write to the SD card (DON'T MODIFY THIS FUNCTION)
void writeFile(fs::FS &fs, const char * path, const char * message) {
  Serial.printf("Writing file: %s\n", path);

  File file = fs.open(path, FILE_WRITE);
  if(!file) {
    Serial.println("Failed to open file for writing");
    return;
  }
  if(file.print(message)) {
    Serial.println("File written");
  } else {
    Serial.println("Write failed");
  }
  file.close();
}

// Append data to the SD card (DON'T MODIFY THIS FUNCTION)
void appendFile(fs::FS &fs, const char * path, const char * message) {
  Serial.printf("Appending to file: %s...", path);

  File file = fs.open(path, FILE_APPEND);
  if(!file) {
    Serial.println("Failed to open file for appending");
    return;
  }
  if(file.print(message)) {
    Serial.println("Message appended");
  } else {
    Serial.println("Append failed");
  }
  file.close();
}

void printLocalTime(void){
  struct tm timeinfo;
  if(!getLocalTime(&timeinfo)){
    Serial.println("Failed to obtain time");
    return;
  }
  Serial.println(&timeinfo, "%A, %B %d %Y %H:%M:%S");
}
